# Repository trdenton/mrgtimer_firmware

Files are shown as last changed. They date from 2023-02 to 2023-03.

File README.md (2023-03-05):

# mrgtimer\_firmware
firmware for Manitoba Robot Games timer board

# Prerequisites

Use arduino 1.8... newer versions might work too

Install DFRobot LCD library.  In Arduino IDE, go to "Tools > Manage Libraries..."

Search for DFRobot LCD and install DFRobot\_RGBLCD1602 v2.0.0

# Directories

## old\_sketches/race\_timer

This is the original Arduino sketch by Bruce

## old\_sketches/mrg\_timer

This is some work done by Troy, wholly ignorant of the previous work done by Bruce

## mrgtimer\_firmware

This is the functioning sketch, a combination of the above two works

## kicad

board design files

# Compilation

open the mrgtimer\_firmware project in the arduino ide

this can be done with `make gui` (read the Makefile for instructions)

ensure the board type is set to 'Arduino Nano' (atmega328p variant)

# Compilation w/ arduino-cli

Install arduino cli
install avr core: ~/Software/arduino-cli core install arduino:avr
now you can use the following:
make verify
make upload

# Known Issues

Pins A6 and A7 cannot be used as outputs - these drive the finish lights

possible workaround: patch S0 and S1 to A6 and A7 respectively, drive those pins instead.
would lose SPI ability though.

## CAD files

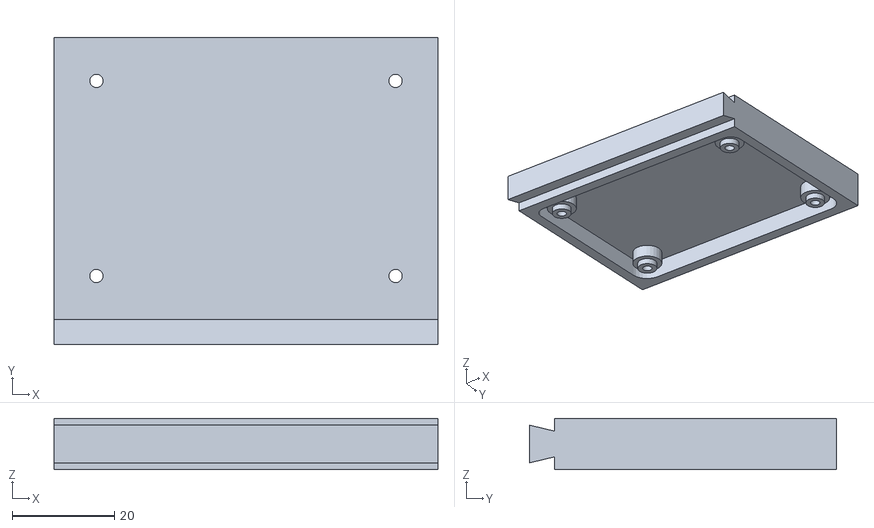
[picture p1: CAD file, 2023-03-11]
models/gate_mount_main.stl
75.0 x 59.9 x 10.0

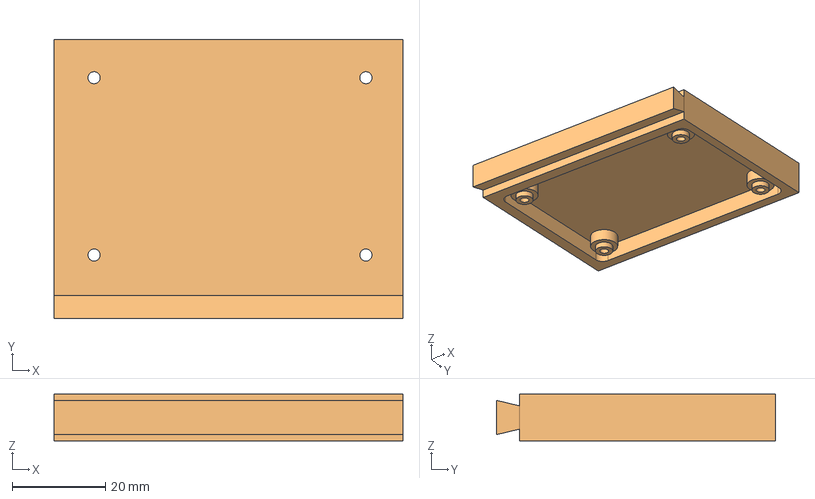
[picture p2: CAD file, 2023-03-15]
models/gate_mount.FCStd
75.0 x 59.9 x 10.0 mm

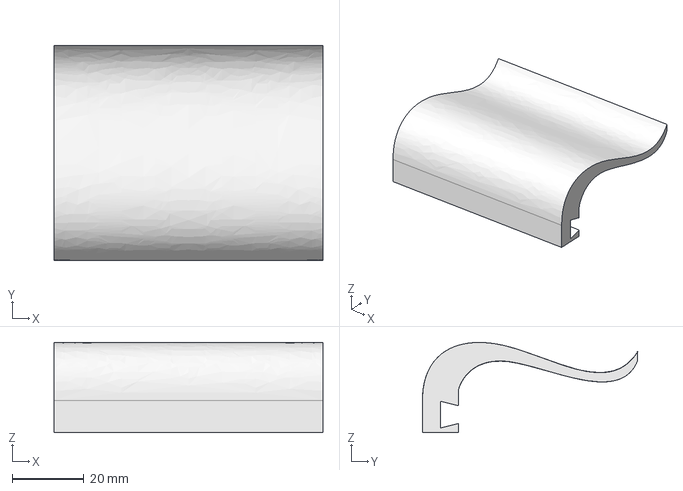
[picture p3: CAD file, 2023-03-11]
models/clip.FCStd
75.0 x 60.0 x 25.1 mm

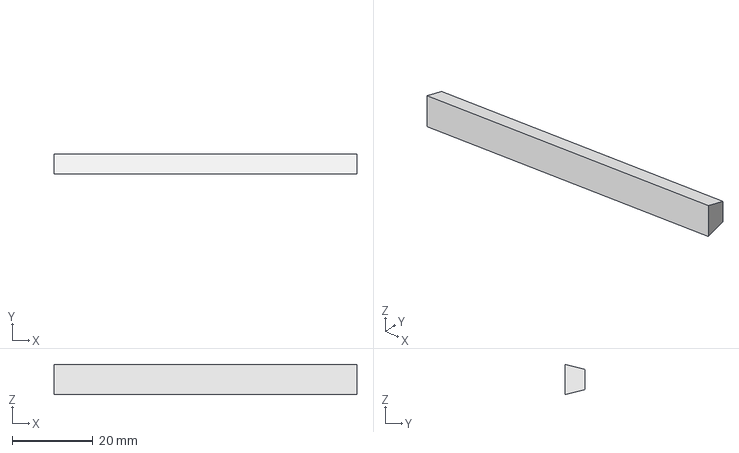
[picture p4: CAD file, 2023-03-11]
models/dovething.FCStd
75.0 x 5.00 x 7.50 mm

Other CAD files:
models/gate_mount_clip.stl

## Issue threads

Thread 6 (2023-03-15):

bad calibration error message is very short on lcd

trdenton, 2023-03-15:

Closed 2023-03-15.

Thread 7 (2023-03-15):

timer does not check that start gates are crossed before end gates

trdenton, 2023-03-15:
is this an issue? if we break the beam on the end gates without first transiting the start gate, it considers that the race time, it should probably be an error condition

trdenton, 2023-03-15:
this implies that the start gate didnt work... which could mean a false start wasnt caught.  create an error for this state

trdenton, 2023-03-15:
on second thought - ordering is enforced by the way we optimize analogMonitor.  we dont even read the finish sensor until we trip the start gate.  addressed in 296ecac

Closed 2023-03-15.

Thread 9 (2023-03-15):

calibration does not detect fail on the first run

trdenton, 2023-03-15:
e.g. if one of the sensors is obstructed on the first run (in simulation) it does not catch an issue

Closed 2023-03-15.

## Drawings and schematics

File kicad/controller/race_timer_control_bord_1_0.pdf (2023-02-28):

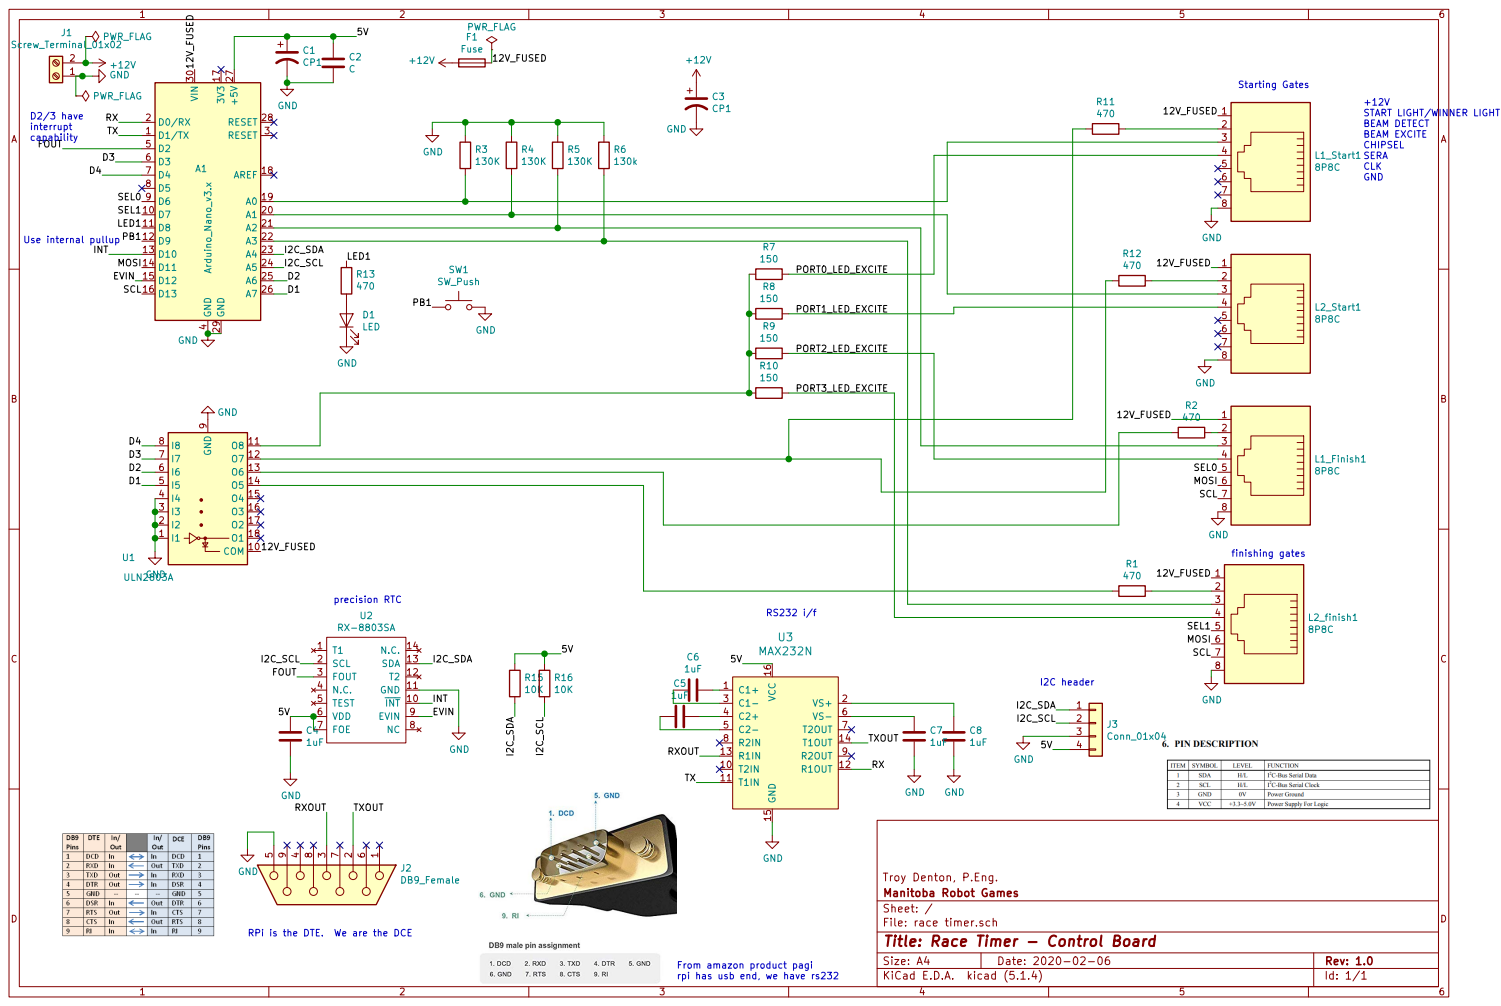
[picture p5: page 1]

START LIGHT/WINNER LIGHT BEAM DETECT BEAM EXCITE CHIPSEL SERA CLK GND

5 6 7 8

rpi has usb end, we have rs232 RS232 i/f precision RTC

File: race timer.sch Sheet: / Manitoba Robot Games Troy Denton, P.Eng. C5

Id: 1/1 Title: Race Timer - Control Board

RPi is the DTE. We are the DCE

From amazon product pagi

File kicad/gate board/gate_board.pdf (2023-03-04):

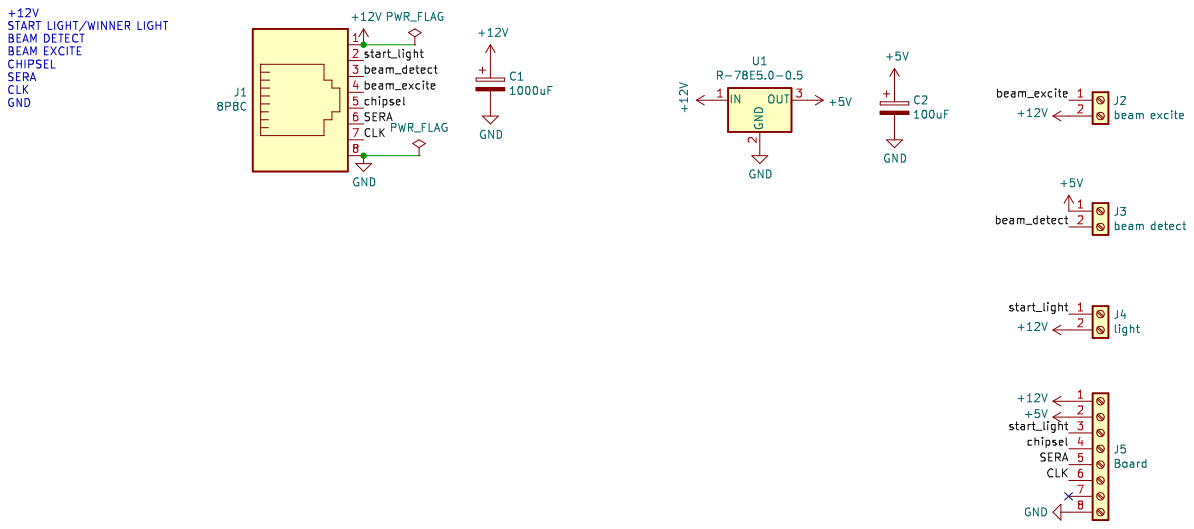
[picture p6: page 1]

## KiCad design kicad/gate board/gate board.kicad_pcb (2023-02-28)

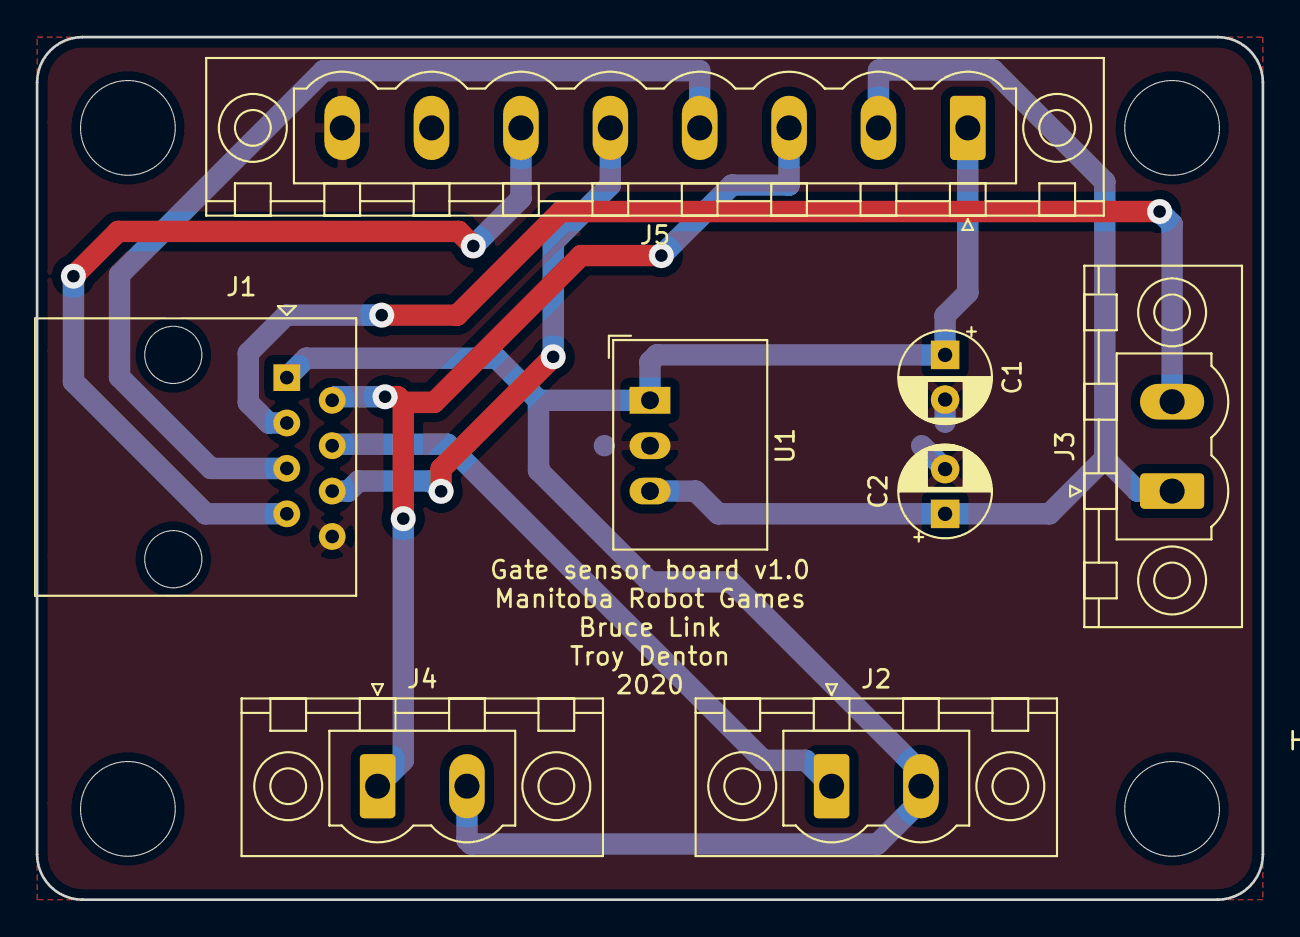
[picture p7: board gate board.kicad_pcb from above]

Board: 2 copper layers, 68.6 x 48.3 mm, 12 parts (0 on the bottom side), 9 nets.

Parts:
C1: 1000uF; CP_Radial_D5.0mm_P2.50mm
C2: 100uF; CP_Radial_D5.0mm_P2.50mm
HOLE1, HOLE2, HOLE3, HOLE4: MountingHole_5.3mm_M5
J1: 8P8C; RJ45_Amphenol_54602-x08_Horizontal
J2: beam excite; PhoenixContact_MSTBV_2,5_2-GF_1x02_P5.00mm_Vertical_Threade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
J3: beam detect; PhoenixContact_MSTBV_2,5_2-GF_1x02_P5.00mm_Vertical_Threade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
J4: light; PhoenixContact_MSTBV_2,5_2-GF_1x02_P5.00mm_Vertical_Threade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
J5: Board; PhoenixContact_MSTBV_2,5_8-GF_1x08_P5.00mm_Vertical_Threade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
U1: R-78E5.0-0.5; Converter_DCDC_RECOM_R-78E-0.5_THT

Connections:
+5V: C2.1, J3.1, J5.2, U1.3
+12V: C1.1, J1.1, J2.2, J4.2, J5.1, U1.1
/CLK: J1.7, J5.6
/SERA: J1.6, J5.5
/beam_detect: J1.3, J3.2
/beam_excite: J1.4, J2.1
/chipsel: J1.5, J5.4
/start_light: J1.2, J4.1, J5.3
GND: C1.2, C2.2, J1.8, J5.8, U1.2

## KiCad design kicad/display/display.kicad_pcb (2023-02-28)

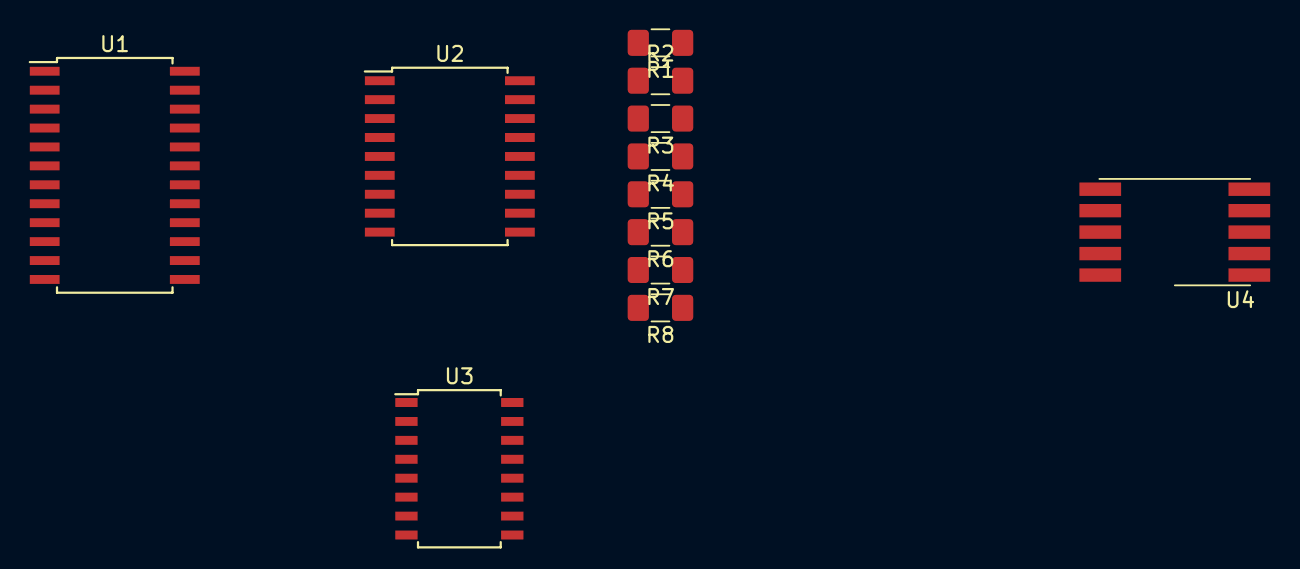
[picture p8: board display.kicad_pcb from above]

Board: 2 copper layers, 12 parts (0 on the bottom side), 28 nets, no tracks yet.

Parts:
R1, R2, R3, R4, R5, R6, R7, R8: R; R_1206_3216Metric_Pad1.42x1.75mm_HandSolder
U1: MAX7219; SOIC-24W_7.5x15.4mm_P1.27mm
U2: TBD62783A-NPN; SOIC-18W_7.5x11.6mm_P1.27mm
U3: SN75374D; SOIC-16W_5.3x10.2mm_P1.27mm
U4: KCSA02-105; KCSC02-105

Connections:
+5V: U1.19, U3.16
+12V: U2.9, U3.1, U3.9
GND: U1.4, U1.9, U2.10, U3.8
unnamed: R1.1, U4.7
unnamed: R1.2, U2.18
unnamed: R2.1, U4.6
unnamed: R2.2, U2.17
unnamed: R3.1, U4.4
unnamed: R3.2, U2.16
unnamed: R4.1, U4.2
unnamed: R4.2, U2.15
unnamed: R5.1, U4.1
unnamed: R5.2, U2.14
unnamed: R6.1, U4.9
unnamed: R6.2, U2.13
unnamed: R7.1, U4.10
unnamed: R7.2, U2.12
unnamed: R8.1, U4.5
unnamed: R8.2, U2.11
unnamed: U1.14, U2.1
unnamed: U1.15, U2.6
unnamed: U1.16, U2.2
unnamed: U1.17, U2.7
unnamed: U1.20, U2.3
unnamed: U1.21, U2.5
unnamed: U1.22, U2.8
unnamed: U1.23, U2.4
unnamed: U4.3, U4.8

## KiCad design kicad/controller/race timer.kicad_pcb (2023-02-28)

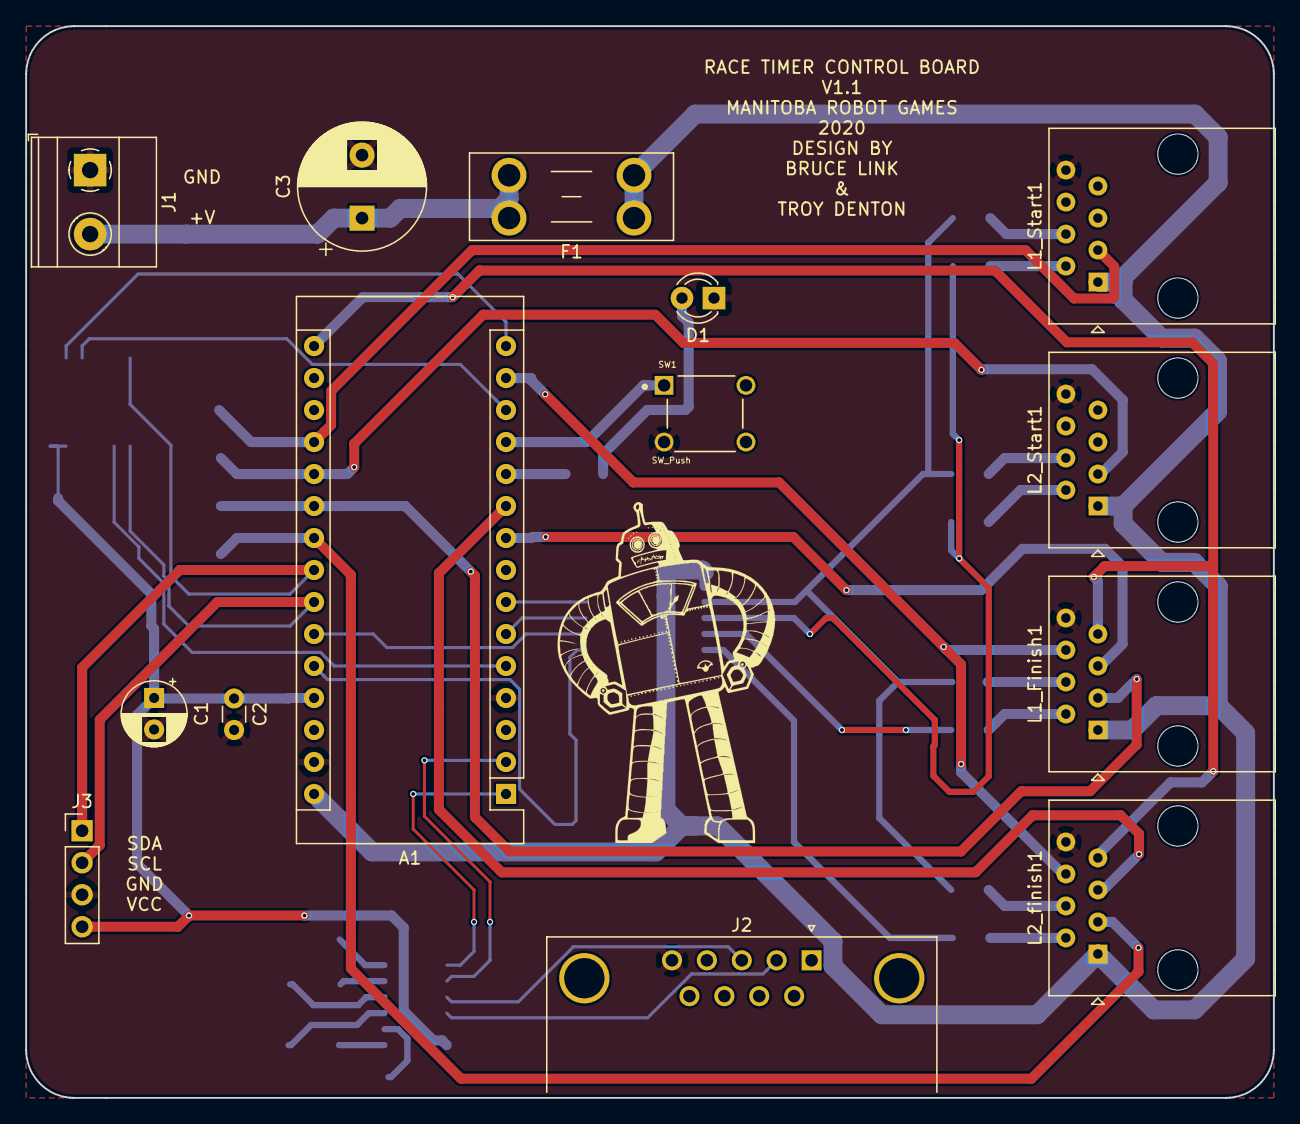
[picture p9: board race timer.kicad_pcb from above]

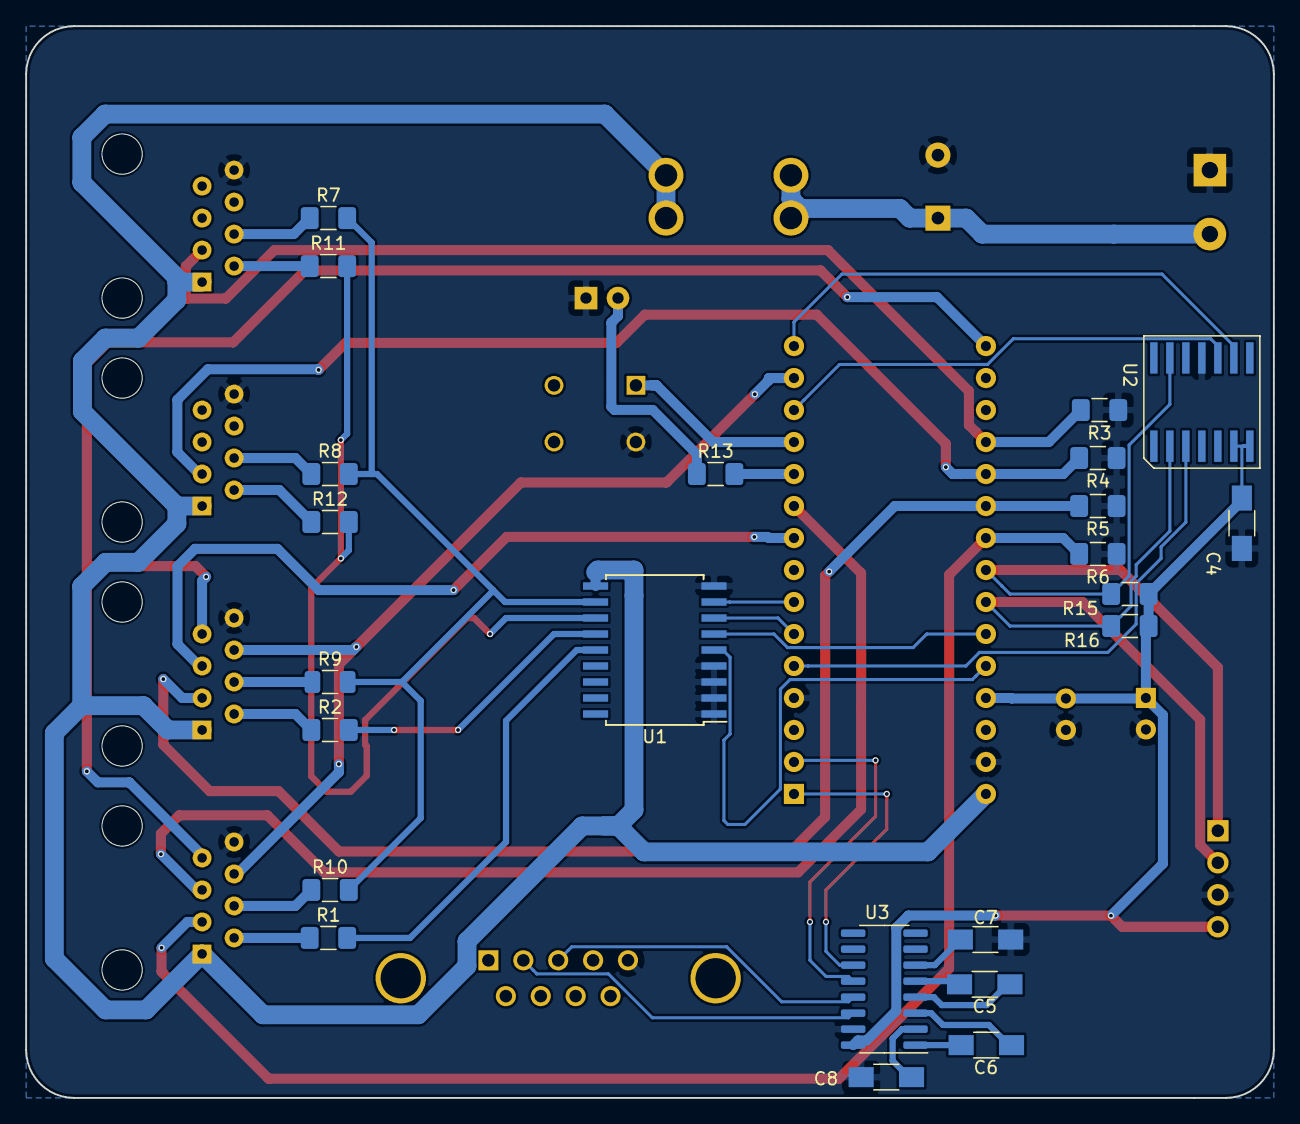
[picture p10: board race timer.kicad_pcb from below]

Board: 2 copper layers, 99.1 x 85.1 mm, 37 parts (23 on the bottom side), 46 nets.

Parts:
A1: Arduino_Nano_v3.x; Arduino_Nano
C1: CP1; CP_Radial_D5.0mm_P2.50mm
C2: C; C_Disc_D3.0mm_W1.6mm_P2.50mm
C3: CP1; CP_Radial_D10.0mm_P5.00mm
C4, C5, C6, C7, C8: 1uF; C_1206_HandSoldering
D1: LED; LED_D3.0mm
F1: Fuse; Fuseholder_Blade_Mini_Keystone_3568
J1: Screw_Terminal_01x02; TerminalBlock_Phoenix_MKDS-1,5-2-5.08_1x02_P5.08mm_Horizont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
J2: DB9_Female; DSUB-9_Female_Horizontal_P2.77x2.84mm_EdgePinOffset7.70mm_H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
J3: Conn_01x04; PinHeader_1x04_P2.54mm_Vertical
L1_Finish1, L1_Start1, L2_Start1, L2_finish1: 8P8C; RJ45_Amphenol_54602-x08_Horizontal
R1, R2, R11, R12, R13: 470; R_1206_3216Metric_Pad1.42x1.75mm_HandSolder
R3, R4, R5: 130K; R_1206_3216Metric_Pad1.42x1.75mm_HandSolder
R6: 130k; R_1206_3216Metric_Pad1.42x1.75mm_HandSolder
R7, R8, R10: 150; R_1206_3216Metric_Pad1.42x1.75mm_HandSolder
R9: 150; R_1206_3216Metric
R15, R16: 10K; R_1206_3216Metric_Pad1.42x1.75mm_HandSolder
SW1: SW_Push; SW_2-1825910-7
U1: ULN2803A; SOIC-18W_7.5x11.6mm_P1.27mm
U2: RX-8803SA; SOIC-14
U3: MAX232N; SOIC-16_3.9x9.9mm_P1.27mm

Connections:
+12V: C3.1, F1.2, J1.2
/5V: A1.27, C1.1, C2.1, C4.1, J3.4, R15.1, R16.1, U2.6, U2.7, U3.16
/12V_FUSED: A1.30, F1.1, L1_Finish1.1, L1_Start1.1, L2_Start1.1, L2_finish1.1, U1.10
/D1: A1.26, U1.5
/D2: A1.25, U1.6
/D3: A1.6, U1.7
/D4: A1.7, U1.8
/EVIN: A1.15, U2.9
/FOUT: A1.5, U2.3
/I2C_SCL: A1.24, J3.2, R16.2, U2.2
/I2C_SDA: A1.23, J3.1, R15.2, U2.13
/INT: A1.13, U2.10
/LED1: A1.11, R13.2
/MOSI: A1.14, L1_Finish1.6, L2_finish1.6
/PB1: A1.12, SW1.1
/PORT0_LED_EXCITE: L1_Start1.4, R7.1
/PORT1_LED_EXCITE: L2_Start1.4, R8.1
/PORT2_LED_EXCITE: L1_Finish1.4, R9.1
/PORT3_LED_EXCITE: L2_finish1.4, R10.1
/RX: A1.2, U3.12
/RXOUT: J2.3, U3.13
/SCL: A1.16, L1_Finish1.7, L2_finish1.7
/SEL0: A1.9, L1_Finish1.5
/SEL1: A1.10, L2_finish1.5
/TX: A1.1, U3.11
/TXOUT: J2.2, U3.14
GND: A1.4, A1.29, C1.2, C2.2, C3.2, C4.2, C7.2, C8.2, D1.1, J1.1, J2.5, J3.3, L1_Finish1.8, L1_Start1.8, L2_Start1.8, L2_finish1.8, R3.1, R4.1, R5.1, R6.1, SW1.2, U1.1, U1.2, U1.3, U1.4, U1.9, U2.11, U3.15
unnamed: A1.19, L1_Start1.3, R3.2
unnamed: A1.20, L2_Start1.3, R4.2
unnamed: A1.21, L1_Finish1.3, R5.2
unnamed: A1.22, L2_finish1.3, R6.2
unnamed: C5.1, U3.4
unnamed: C5.2, U3.5
unnamed: C6.1, U3.1
unnamed: C6.2, U3.3
unnamed: C7.1, U3.6
unnamed: C8.1, U3.2
unnamed: D1.2, R13.1
unnamed: L1_Finish1.2, R2.1
unnamed: L1_Start1.2, R11.1
unnamed: L2_Start1.2, R12.1
unnamed: L2_finish1.2, R1.1
unnamed: R1.2, U1.14
unnamed: R2.2, U1.13
unnamed: R7.2, R8.2, R9.2, R10.2, U1.11
unnamed: R11.2, R12.2, U1.12

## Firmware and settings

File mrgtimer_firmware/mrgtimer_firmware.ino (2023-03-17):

#include <string.h>
#include <limits.h>
#include "rx8803.h"
#include "lcd.h"

/****************
 *
 * DEFINES
 *
 ****************/


#define WTF(_X_) do {Serial.print("Something weird on ");Serial.print(__LINE__);Serial.print(": ");Serial.println(_X_);} while(0);

#define PULSE_BUFFER_SIZE 16
#define NUMBER_LANES 2

#define TIMER_CLK_PIN 2
#define STARTER_BUTTON_PIN 9  // button input
#define STARTER_LIGHT_PIN 3   // This is the inhibit signal that stops car from moving
#define GATE_LIGHT_PIN 4      // This is what drives the sensor LEDs

#define LANE_1_FALSE_START_PIN A0
#define LANE_2_FALSE_START_PIN A1

#define LANE_1_FINISH_PIN A2
#define LANE_2_FINISH_PIN A3

#define LANE_1_WIN_LIGHT_PIN A6 // BUG: A6 cannot output :(
#define LANE_2_WIN_LIGHT_PIN A7 // BUG: A7 cannot output :(

#define LONG_PRESS_DURATION 2000

#define ERROR_MESSAGE_MS 5000

//Debug symbols.
#define DEBUG 1
#define LOG_DEBUG 9
#define LOG_EVENTS 8

#define RX_BUFF_LEN (32)

/**************************
 *
 * STRUCTS, ENUMS
 *
 *************************/

enum timer_state {
  STATE_IDLE,             
  STATE_IDLE_WAIT,        
  STATE_CALIBRATE_ANALOG, 
  STATE_CALIBRATE_SETTLE,
  STATE_STARTING,         
  STATE_STARTING_WAIT,    
  STATE_RUNNING,          
  STATE_RUNNING_WAIT,     
  STATE_PRE_START_FAILED, 
  STATE_FALSE_START,      
  STATE_FINISHED,         
  STATE_FINISHED_WAIT,    
  STATE_TEST_GATE,        
  STATE_TEST_CALIBRATE_ANALOG,
  STATE_TEST_MONITOR_ANALOG,
  NUM_TIMER_STATES
};

typedef enum{
  STATE_BUTTON_UP,
  STATE_BUTTON_DOWN,
  STATE_BUTTON_LONG,
} button_state;

enum win_light_state {
  STATE_WIN_LIGHT_WAIT,
  STATE_WIN_LIGHT_WON,
};

struct discrete_input {
  long debounce_delay;
  bool last_value;
  long count;
  //bool value;
  int pin;
  button_state state;
  int short_presses;
  int long_presses;
  unsigned long button_down_time;
  bool invert;
};

struct analog_gate {
  int pulse_index;
  volatile int16_t pulse_buffer[PULSE_BUFFER_SIZE];
  int last_raw_value;
  unsigned long break_time;
  int pin;
  int threshold;
  int valid_readings;
  bool value;
  char gate;
};

struct race_lane {
  struct analog_gate false_start_sensor;
  struct analog_gate finish_line_sensor;
  int reaction_time;
  long unsigned int finish_time;
  char title;
};


/****************
 *
 * GLOBAL VARS
 *
 ****************/


// receiving commands
bool stringComplete = false;
char buff[RX_BUFF_LEN] = {0};
int buff_idx = 0;

race_lane lane[NUMBER_LANES];

char* c = new char[80];

//struct analog_gate *analog_gates[ANALOG_CHANNEL_COUNT];

enum timer_state state;
enum win_light_state win_state;

unsigned long step_time;
bool test_last_value = false;
//int active_analog_channel;

discrete_input start_button;

int sensor_value = 0;
int cycle = 0;
int change_counter = 0;

volatile int current_channel = 0;
volatile bool light_state = false;

unsigned long sweep_time;
unsigned long last_time;
unsigned long last_lcd_update;

//const char* states[] = {
//  "STATE_IDLE",
//  "STATE_IDLE_WAIT",
//  "STATE_CALIBRATE_ANALOG",
//  "STATE_CALIBRATE_SETTLE",
//  "STATE_STARTING",
//  "STATE_STARTING_WAIT",
//  "STATE_RUNNING",
//  "STATE_RUNNING_WAIT",
//  "STATE_PRE_START_FAILED",
//  "STATE_FALSE_START",
//  "STATE_FINISHED",
//  "STATE_FINISHED_WAIT",
//  "STATE_TEST_GATE",
//  "STATE_TEST_CALIBRATE_ANALOG",
//  "STATE_TEST_MONITOR_ANALOG"
//};


/****************
 *
 * FUNCTIONS
 *
 ****************/

//void announce_state() {
//  static enum timer_state last;
//  static int first = 1;
//
//  if ((last != state) || first) {
//    Serial.print("STATE: "); Serial.println(states[state]);
//    first = 0;
//  }
//  last = state;
//}

void setup() {
  Serial.begin(9600); //119200
  // pin configurations:
  pinMode(TIMER_CLK_PIN, INPUT);
  pinMode(STARTER_BUTTON_PIN, INPUT_PULLUP);
  pinMode(LANE_1_FALSE_START_PIN, INPUT);
  pinMode(LANE_2_FALSE_START_PIN, INPUT);
  pinMode(LANE_1_FINISH_PIN, INPUT);
  pinMode(LANE_2_FINISH_PIN, INPUT);

  pinMode(GATE_LIGHT_PIN, OUTPUT);
  pinMode(STARTER_LIGHT_PIN, OUTPUT);
  pinMode(LANE_1_WIN_LIGHT_PIN, OUTPUT);
  pinMode(LANE_2_WIN_LIGHT_PIN, OUTPUT);


  rx8803_init(TIMER_CLK_PIN);
  lcd_init();



  start_button.debounce_delay = 50000; //us
  start_button.pin = STARTER_BUTTON_PIN;
  start_button.invert = true;
  start_button.short_presses = 0;
  start_button.long_presses = 0;
  start_button.state = STATE_BUTTON_UP;

  lane[0].false_start_sensor.pin = LANE_1_FALSE_START_PIN;
  lane[0].false_start_sensor.pulse_index = 0;
  lane[0].false_start_sensor.value = 0;
  lane[0].false_start_sensor.threshold = 0;
  lane[0].false_start_sensor.gate = 's';
  lane[0].false_start_sensor.valid_readings = 0;

  lane[0].finish_line_sensor.pin = LANE_1_FINISH_PIN;
  lane[0].finish_line_sensor.pulse_index = 0;
  lane[0].finish_line_sensor.value = 0;
  lane[0].finish_line_sensor.threshold = 0;
  lane[0].finish_line_sensor.gate = 'f';
  lane[0].finish_line_sensor.valid_readings = 0;

  lane[0].title = '1';

  lane[1].false_start_sensor.pin = LANE_2_FALSE_START_PIN;
  lane[1].false_start_sensor.pulse_index = 0;
  lane[1].false_start_sensor.value = 0;
  lane[1].false_start_sensor.threshold = 0;
  lane[1].false_start_sensor.gate = 's';
  lane[1].false_start_sensor.valid_readings = 0;

  lane[1].finish_line_sensor.pin = LANE_2_FINISH_PIN;
  lane[1].finish_line_sensor.pulse_index = 0;
  lane[1].finish_line_sensor.value = 0;
  lane[1].finish_line_sensor.threshold = 0;
  lane[1].finish_line_sensor.gate = 'f';
  lane[1].finish_line_sensor.valid_readings = 0;

  lane[1].title = '2';

  last_time = micros();
  winLightReset();
  lcd_message("MRGTimer v0.1");
  Serial.println("System Reset");
  
  state = STATE_IDLE;
  Serial.println("STATE: STATE_IDLE");
  
  delay(3000);
}


void loop() {
  bool b;

//  announce_state();

  //get the sweep time in us.
  sweep_time = micros() - last_time;
  last_time = micros();

  //condition the start button
  debounce(&start_button);

  
  if (start_button.long_presses > 0) {
    start_button.long_presses = 0;
    state = STATE_IDLE;
    Serial.println("STATE: STATE_IDLE");
  }

  //condition the inputs.
  for (int i = 0; i < NUMBER_LANES; i++) {
    switch(state) {
      case STATE_RUNNING:
      case STATE_RUNNING_WAIT:
        // only read start gate if we havnt crossed it yet
        if (lane[i].reaction_time == -1) {
          analogMonitor(&(lane[i].false_start_sensor));
        } else {
          analogMonitor(&(lane[i].finish_line_sensor));
        }
        break;
        
      case STATE_STARTING_WAIT:
        analogMonitor(&(lane[i].false_start_sensor));
        break;
        
      case STATE_IDLE:
      case STATE_IDLE_WAIT:  
      case STATE_STARTING:
      case STATE_CALIBRATE_ANALOG:
      case STATE_CALIBRATE_SETTLE:
      case STATE_TEST_GATE:
      case STATE_TEST_CALIBRATE_ANALOG:
      case STATE_TEST_MONITOR_ANALOG:
        analogMonitor(&(lane[i].finish_line_sensor));
        analogMonitor(&(lane[i].false_start_sensor));
        break;
      default:
        break;
    }
  }

  // flip the light.
  light_state = !light_state;// && (state != STATE_IDLE_WAIT);
  digitalWrite(GATE_LIGHT_PIN, light_state);
  delay(1); //wait for the light state to change **IMPORTANT**


  //*************************************************
  //State machine processing.
  //*************************************************

  
  if (STATE_IDLE == state) {
    winLightReset();
    digitalWrite(STARTER_LIGHT_PIN, HIGH);
    start_button.long_presses = 0;
    start_button.short_presses = 0;

    state = STATE_IDLE_WAIT;
    Serial.println("STATE: STATE_IDLE_WAIT");
    
    lcd_message("Ready");
  }

  else if (STATE_IDLE_WAIT == state) {
    if (0 < start_button.short_presses) {
      // Start button pressed, transition to the starting state

      state = STATE_CALIBRATE_ANALOG;
      lcd_message("Calibrating...");
      cycle = 0;
    }
  }

  else if (STATE_CALIBRATE_ANALOG == state) {
    cycle++; // number of cycles/samples collected
    if (cycle < PULSE_BUFFER_SIZE) {
      b = 1;
      for (int i = 0; i < NUMBER_LANES; i++ ) {
        calibrateAnalog(&lane[i].false_start_sensor);
        calibrateAnalog(&lane[i].finish_line_sensor);
        if(lane[i].false_start_sensor.threshold < 10){
          lcd_message("L%cS GATE FAULT");
          b = 0;
        }
        else if(lane[i].finish_line_sensor.threshold < 10){
          lcd_message("L%cF GATE FAULT");
          b = 0;
        }
      }
      if(!b){
        Serial.println("STATE: PRE_START_FAILED");
        state = STATE_PRE_START_FAILED;
      } else {
        state = STATE_CALIBRATE_SETTLE;
        Serial.println("STATE: STATE_CALIBRATE_SETTLE");
        
        lcd_message("Settling...");
        step_time = millis();
      }
    }
  }

  else if (STATE_CALIBRATE_SETTLE == state) {
    b = 1;
    for (int i = 0; i < NUMBER_LANES; i++) {
      b = b && (lane[i].finish_line_sensor.valid_readings == PULSE_BUFFER_SIZE) &&
        (lane[i].false_start_sensor.valid_readings == PULSE_BUFFER_SIZE);
    }
    if(b){
      state = STATE_STARTING;
      Serial.println("STATE: STATE_STARTING");
    }
  }

  else if (STATE_STARTING == state) {
    start_button.long_presses = 0;
    start_button.short_presses = 0;

    // Verify that all the lights are on and feedback is correct before starting the race.
    b = 1;
    for (int i = 0; i < NUMBER_LANES; i++ ) {
      if (!lane[i].finish_line_sensor.value) {
        sprintf(c, "lane %c finish line sensor obstructed", lane[i].title);
        lcd_message("L%c Finish fail");
        Serial.println(c);
        b = 0;
      }
      if (!lane[i].false_start_sensor.value) {
        sprintf(c, "lane %c false start sensor obstructed", lane[i].title);
        lcd_message("L%c Start fail");
        Serial.println(c);
        b = 0;
      }
    }

    if (b) {
      // All sensors reading correctly
      step_time = random(3, 5)*1000; // This is when the race will start.
      state = STATE_STARTING_WAIT;
      Serial.println("STATE: STATE_STARTING_WAIT");
      sprintf(c, "Start delay is %i ms", step_time);
      Serial.println(c);
      step_time += millis();

    } else {
      if (millis() > step_time) {
        step_time = millis() + ERROR_MESSAGE_MS;
        state = STATE_PRE_START_FAILED;
        Serial.println("STATE: STATE_STARTING - Sensors not reading correctly");
      }
    }
  }
  else if (STATE_STARTING_WAIT == state) {
    if (millis() > step_time) {
      // start the race.
      state = STATE_RUNNING;
      Serial.println("STATE: STATE_RUNNING");
    } else {
      unsigned long countdown = step_time - millis();
      sprintf(c, "%d...", (1000+countdown)/1000);
      lcd_message(c);
    }

    // on the lookout for false starts.
    for (int i = 0; i < NUMBER_LANES; i++ ) {
      if (0 == lane[i].false_start_sensor.value) {
        //print a message indicating false start
        sprintf(c, "L%c FALSE START", lane[i].title);
        Serial.println(c);
        
        state = STATE_FALSE_START;
        Serial.println("STATE: STATE_FALSE_START");
        
        step_time = millis() + ERROR_MESSAGE_MS;
        lcd_message(c);
      }
    }
  }

  else if (STATE_RUNNING == state) {
    lcd_message("GO!!!!!");
    start_button.long_presses = 0;
    start_button.short_presses = 0;

    for (int i = 0; i < NUMBER_LANES; i++ ) {
      lane[i].reaction_time = -1;
      lane[i].finish_time = ULONG_MAX;
    }

    state = STATE_RUNNING_WAIT;
    Serial.println("STATE: STATE_RUNNING_WAIT");
    step_time = millis();

    // drop the flag.
    digitalWrite(STARTER_LIGHT_PIN, LOW);
    rx8803_start_counter();
    last_lcd_update = 0;
  }

  else if (STATE_RUNNING_WAIT == state) {
    bool done = true;
    
    for (int i = 0; i < NUMBER_LANES; i++ ) {
      // Measure reaction time.
      if ((-1 == lane[i].reaction_time) && (0 == lane[i].false_start_sensor.value)) {
        lane[i].reaction_time = lane[i].false_start_sensor.break_time - step_time;
        sprintf(c, "Lane %c reacted in %d ms", lane[i].title, lane[i].reaction_time);
        Serial.println(c);
      }

      // Measure finish time.
      if ((ULONG_MAX == lane[i].finish_time) && (0 == lane[i].finish_line_sensor.value)){
          lane[i].finish_time = rx8803_get_count();
          winLightLatch(i);
          sprintf(c, "Lane %c: %d ms", lane[i].title, lane[i].finish_time);
          Serial.println(c);
          lcd_result(i, lane[i].finish_time);
      }

      // Make sure both lanes have finished.
      if (ULONG_MAX == lane[i].finish_time) {
        done = false;
      }
    }
    
    if (done) {
      rx8803_stop_counter();
      
      Serial.println("STATE: STATE_RUNNING_WAIT");
      state = STATE_FINISHED;
    } else {
      int time_row = 0;
      if (ULONG_MAX != lane[0].finish_time) {
        time_row = 1;
      }
      if((millis() - last_lcd_update) > 100){
        lcd_elapsed(time_row, rx8803_get_count());
        last_lcd_update = millis();
      }
    }
  }

  else if (STATE_FINISHED == state) {
    start_button.long_presses = 0;
    start_button.short_presses = 0;
    
    Serial.println("STATE: STATE_FINISHED_WAIT");
    state = STATE_FINISHED_WAIT;
  }

  else if (STATE_FINISHED_WAIT == state) {
    if (0 < start_button.short_presses) {
      // Start button pressed, transition to the starting state
      state = STATE_IDLE;
      Serial.println("STATE: STATE_IDLE");
    }
  }

  else if (STATE_PRE_START_FAILED == state) {
    lcd_message("Cal fail :(");
    // Not able to sucessfully see all the light gates.
    // ensure we are displaying the message for a while
    if (millis() > step_time) {
      state = STATE_IDLE;
      Serial.println("STATE: STATE_IDLE");
    }
  }

  else if (STATE_FALSE_START == state) {
    // Somebody jumped the gun.
    // lcd already has message, wait for keypress
    if (0 < start_button.short_presses) {
      // Start button pressed, transition to the starting state
      state = STATE_IDLE;
      Serial.println("STATE: STATE_IDLE");
    }
  }

  // this is populated by serialEvent()
  if (stringComplete) {
    processCommand();
    stringComplete = false;
  }
}

void calibrateAnalog(struct analog_gate *ag) {
  int i;
  int j;
  
  // find out the average difference reading.
  j = 0;
  for (i = 1; i < PULSE_BUFFER_SIZE; i++) {
      j += ag->pulse_buffer[i];
  }
  j /= PULSE_BUFFER_SIZE;

  // The threshold is the value of change at which the light is considered not visible.
  // probably should calculate the noise level on the signal and use that but that's for
  // another day.
  ag->threshold = j / 2;

  if (DEBUG) {
    sprintf(c, "calibration for analog pin: %i ", ag->pin);
    Serial.println(c);

    sprintf(c, "Gate: %c Threshold: %d ", ag->gate, ag->threshold);
    for (i = 0; i < PULSE_BUFFER_SIZE; i++) {
      j = (ag->pulse_index + PULSE_BUFFER_SIZE - i) % PULSE_BUFFER_SIZE;
      sprintf(c + strlen(c), "%d ", ag->pulse_buffer[j]);
    }
    Serial.println(c);
    ag->valid_readings = 0;
  }
}

void analogMonitor(struct analog_gate *ag) {
  int i;
  int k;

  // Record the current light level and store the difference between it and the last light level.
  // Store the current light level in the last_value for the next evaluation.

  i = analogRead(ag->pin);
  ag->pulse_index++;
  ag->pulse_index %= PULSE_BUFFER_SIZE;
  ag->pulse_buffer[ag->pulse_index] = abs(ag->last_raw_value - i);
  ag->last_raw_value = i;

  // Count the number of times that change is detected between samples.
  k = 0;
  for (i = 0; i < PULSE_BUFFER_SIZE; i++) {
    if (ag->pulse_buffer[i] > ag->threshold) {
      // Saw a big enough change in value
      k++;
    }
  }
  ag->valid_readings++;
  if(ag->valid_readings > PULSE_BUFFER_SIZE){
    ag->valid_readings = PULSE_BUFFER_SIZE;
    i = 1;
  }else{
    i = 0;
  }
  
  // See if we should transition from high to low.
  if(i && (ag->value == 1) && ((PULSE_BUFFER_SIZE - k) >  (PULSE_BUFFER_SIZE * 3 / 4))){
    // 3/4 of the buffer saw no change. flip.
    ag->value = 0;
    i = 1;
  }
  
  // See if we should transition from low to high.
  else if(i && (ag->value == 0) && k > (PULSE_BUFFER_SIZE * 3 / 4)){
    // 3/4 of the buffer saw change. flip.
    ag->value = 1;
    i = 1;
  }
  
  else{
    i = 0;
  }
  
  if(i && DEBUG){
    sprintf(c, "pin %d (%c) to %d k: %d", ag->pin, ag->gate, ag->value, k);
    Serial.println(c);
  }
}

void debounce(struct discrete_input *di) {
  bool b;
  b = digitalRead(di->pin);
  b = b ^ di->invert;

  if (b && di->last_value) {
    di->count += sweep_time;
  }
  else if (!b && di->last_value) {
    di->count -= sweep_time / 2;
  }
  else if (b && !di->last_value) {
    di->count += sweep_time /  2;
  }
  else if (!b && !di->last_value) {
    di->count -= sweep_time;
  }

  // clamp the di.count variable.
  if (di->count < 0) {
    di->count = 0;
  }
  if (di->count > di->debounce_delay) {
    di->count = di->debounce_delay;
  }

  // flip the bit if the count exceeds the threshold.
  if (STATE_BUTTON_DOWN == di->state) {
    // Check for a DOWN->UP transition
    if (0 == di->count) {
      //di->value = true;
      if (DEBUG) {
        sprintf(c, "DOWN->UP: Pin %i short press", di->pin);
        Serial.println(c);
      }
      di->short_presses++;
      di->state = STATE_BUTTON_UP;
    }

    // Check for a DOWN->LONG transition
    else if (di->debounce_delay == di->count) {
      if (millis() - di->button_down_time > LONG_PRESS_DURATION) {
        if (DEBUG) {
          sprintf(c, "DOWN->LONG: Pin %i - long press", di->pin);
          Serial.println(c);
        }
        di->long_presses++;
        di->state = STATE_BUTTON_LONG;
      }
    }
  }

  else if (STATE_BUTTON_UP == di->state) {
    // Check for a UP->DOWN transition.
    if (di->debounce_delay == di->count) {
      //di->value = false;
      if (DEBUG) {
        sprintf(c, "UP->DOWN: Digital pin %i to %d", di->pin, b);
        Serial.println(c);
      }
      di->state = STATE_BUTTON_DOWN;
      di->button_down_time = millis();
    }
  }

  else if (STATE_BUTTON_LONG == di->state) {
    // Check for a LONG->UP transition.
    if (0 == di->count) {
      //di->value = false;
      if (DEBUG) {
        sprintf(c, "LONG->UP: Digital pin %i to %d", di->pin, b);
        Serial.println(c);
      }
      di->state = STATE_BUTTON_UP;
    }
  }

  di->last_value = b;
}

// only turn on the winning late e.g. this is stateful
void winLightLatch(int i) {
  if (win_state == STATE_WIN_LIGHT_WAIT) {
    win_state = STATE_WIN_LIGHT_WON;
    digitalWrite( (i == 0) ? LANE_1_WIN_LIGHT_PIN : LANE_2_WIN_LIGHT_PIN , HIGH);
  }
}

void winLightReset() {
  win_state = STATE_WIN_LIGHT_WAIT;
  digitalWrite(LANE_1_WIN_LIGHT_PIN, LOW);
  digitalWrite(LANE_2_WIN_LIGHT_PIN, LOW);
}

// every command must be one line
void serialEvent() {
  static char lastChar;
  while (Serial.available()) {

    // get the new byte:
    char inChar = (char)Serial.read();

    // commands can end in \r or \n or any combo
    if (inChar == '\r' || inChar == '\n') {
      stringComplete = true;
    } else {
      buff[buff_idx] = inChar;
      buff_idx++;
      if (buff_idx == RX_BUFF_LEN) {
        // this really shouldnt happen....
        WTF("shouldnt see input buffer max out");
        reset_buff();
      }
    }
    // if the incoming character is a carriage return (0x0D), set a flag so the main loop can
    // do something about it:
    lastChar = inChar;
  }
}


void ack() {
  Serial.println("ACK");
}

void nack() {
  Serial.println("NACK");
}

void reset_buff() {
  memset(buff,0,RX_BUFF_LEN);
  buff_idx = 0;
}
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

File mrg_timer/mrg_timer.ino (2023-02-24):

/*!
 * @file HelloWorld.ino
 * @brief Show helloworld.
 * @copyright	Copyright (c) 2010 DFRobot Co.Ltd (http://www.dfrobot.com)
 * @licence     The MIT License (MIT)
 * @maintainer [yangfeng](feng.yang@dfrobot.com)
 * @version  V1.0
 * @date  2021-09-24
 * @url https://github.com/DFRobot/DFRobot_RGBLCD1602
 */
#include "DFRobot_RGBLCD1602.h"
#include "rx8803.h"

const int colorR = 255;
const int colorG = 0;
const int colorB = 0;

const int NO_WINNER_YET = -1;

// TODO
// test with hw signals
// test with usb serial
// test with actual serial
// nice to have: control software over serial


enum state {
  STATE_SETUP,
  STATE_COUNTDOWN_START,
  STATE_WAIT,
  STATE_WINNER
};

enum state state;

const int f_in = 2;
const int led_excite = 4; // these control the "motor off" LEDs
const int led_start = 3; 
long unsigned int g_count = 0;

//whatever the count was when we initiate the race
long unsigned int g_t0 = 0;


// indices into arrays for each lanes
const int lane0 = 0;
const int lane1 = 1;

// end times for each lane
long unsigned int g_t1[2] = {0,0};
int win_led[] = {A6, A7};
int beam_in[] = {A2, A3};
int button_in = 9;
int g_winner = NO_WINNER_YET;


DFRobot_RGBLCD1602 lcd(/*lcdCols*/16,/*lcdRows*/2);  //16 characters and 2 lines of show

void setup() {
    state = STATE_SETUP;
    lcd.init();
    pinMode(f_in,INPUT);
    pinMode(led_excite, OUTPUT);
    pinMode(win_led[0], OUTPUT);
    pinMode(win_led[1], OUTPUT);
    pinMode(beam_in[0], INPUT);
    pinMode(beam_in[1], INPUT);
    pinMode(button_in, INPUT_PULLUP);
    /**
     *  @brief initialize the LCD and master IIC
     */ 
    
    // Print a message to the LCD.
    lcd.print("MRGTimer v0.1");
    delay(1000);

    attachInterrupt(digitalPinToInterrupt(f_in), count, RISING);
    
}

// this is the edge triggered interrupt on the precision rtc
void count() {
  g_count++;
}

void beam_excite() {
  digitalWrite(led_excite, LOW);
}

void beam_off() {
  digitalWrite(led_excite, HIGH);
}

void start_race() {
  attachInterrupt(digitalPinToInterrupt(f_in), count, RISING);
  start_light();
  beam_off();
}

void stop_race_counter() {
  detachInterrupt(digitalPinToInterrupt(f_in));
  g_count = 0;
}

void start_light() {
  digitalWrite(led_start, LOW);
}

void winner_light(int i) {
  digitalWrite(win_led[i], LOW);
}

void winner_light_reset() {
  digitalWrite(win_led[0], HIGH);
  digitalWrite(win_led[1], HIGH);
}

void do_countdown() {

  for(int i = 0; i < 3; ++i) {
    lcd.clear();
    lcd.setCursor(0,1);
    lcd.print(3-i);
    winner_light(0); winner_light(1);
    delay(500);
    winner_light_reset();
    delay(500);
  }
}

void blink_winner() {
    for(int i = 0; i < 5; ++i) {
    winner_light(g_winner);
    delay(500);
    winner_light_reset();
    delay(500);
  }
}

int detect_beam() {
  if (digitalRead(beam_in[lane0]) == LOW) {
    return lane0;
  }
  if (digitalRead(beam_in[lane1]) == LOW) {
    return lane1;
  }
  return NO_WINNER_YET;
}

int advance_state() {
  if (digitalRead(button_in)==LOW) {
    while(digitalRead(button_in)==LOW); //wait for it to go back high
    return 1;
  }
  return 0;
}


void check_win(int i) 
{
  int other;
  other = (i == lane0 ? lane1 : lane0 );
  if (0 == g_t1[i] && detect_beam() == i)
  {
    g_t1[i] = g_count;
    if (0 == g_t1[other]) // if the other lane (lane1) hasnt finished, we are the winner
    {
      winner_light(i);
      g_winner = i;
    }
  }
}

void lcd_message(const char* str)
{
  static const char* last = NULL;
  if ( last != str ) {
    lcd.clear();
    lcd.setCursor(0,1);
    lcd.print(str);
  }

  last = str;
}

long unsigned int print_time(int i)
{
  lcd.setCursor(0,i);
  long unsigned int delta = g_t1[i] - g_t0;
  if (0 == g_t1[i]) 
  {
    delta = 0;  
  }
  // 32768 counts is one second
  int minutes = delta / (32768*60);
  int seconds = (delta/ 32768)%60;
  int milliseconds = (delta/33)%1000;
  lcd.print("L"); lcd.print(i); lcd.print(": "); 
  if (minutes < 10)
    lcd.print("0");
  lcd.print(minutes); lcd.print(":"); 

  if (seconds < 10)
    lcd.print("0");
  lcd.print(seconds); lcd.print(".");

  if (milliseconds < 100)
    lcd.print("0");
  if (milliseconds < 10)
    lcd.print("0");
  lcd.print(milliseconds);
}

void show_times()
{
  lcd.clear();
  print_time(lane0);
  print_time(lane1);
}

void loop()
{
  switch(state) {
    case STATE_SETUP:
      lcd_message("SETUP ROBOTS");
      beam_excite();
      g_t1[lane0] = 0;
      g_t1[lane1] = 0;
      stop_race_counter();
      g_winner = NO_WINNER_YET;
      if (advance_state()) {
        state = STATE_COUNTDOWN_START;
      }
    break;
    case STATE_COUNTDOWN_START:
      do_countdown();
      lcd_message("GO!!!");
      start_race();
      state = STATE_WAIT;
    break;
    case STATE_WAIT:
      check_win(lane0);
      check_win(lane1);

      // testing...
      g_t1[0] = g_count;
      g_t1[1] = g_count;

      // wait for both to finish
      // testing...
      if (/*(g_t1[lane0] != 0 && g_t1[lane1] != 0) ||*/ advance_state())
      {
        show_times();
        blink_winner();
        state = STATE_WINNER;
      }
    break;
    case STATE_WINNER:
      if (advance_state())
      {
        state = STATE_SETUP;
      }
    break;
  }
}

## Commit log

2023-02-25 use arduino-cli
2023-02-28 add kicad files
    [controller.dsn, display.kicad_pcb, display.sch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]
2023-02-28 cleanup state printing, add debug commands for timer, add WTF macro
2023-03-04 add gate board schematic
2023-03-05 add lcd test functions, fix time display
    [mrgtimer_firmware.ino]
2023-03-05 fix millisecond output in serial debug
    [mrgtimer_firmware.ino]
2023-03-08 fix lane 2 config, lcd display more messages, add sim target
    [mrgtimer_firmware.ino]
2023-03-11 gate board mount models
    [clip.FCStd, dovething.FCStd, gate_mount.FCStd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]
2023-03-11 ensure extruded part of dovetail fitting is smaller than socket
    [gate_mount.FCStd, gate_mount_main.stl]
2023-03-13 Updated push button logic
2023-03-15 updated .gitignore board bracket
    [gate_mount.FCStd]
2023-03-15 cal fail message persists. add sim_fw make target
    [mrgtimer_firmware.ino]
2023-03-15 fix lcd_message str compare
    [mrgtimer_firmware.ino]
2023-03-15 fix initial cal fail scenario
    [mrgtimer_firmware.ino]
2023-03-15 add timer countdown to display
2023-03-15 only read ADC channels where needed. False start requires button press to proceed
2023-03-16 Slowed LCD update to 10hz
2023-03-16 LCD refresh time to 10Hz
2023-03-17 fix compile error, fix starter light
    [mrgtimer_firmware.ino]
